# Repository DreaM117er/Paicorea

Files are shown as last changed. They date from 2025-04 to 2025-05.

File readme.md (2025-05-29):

# Paicorea

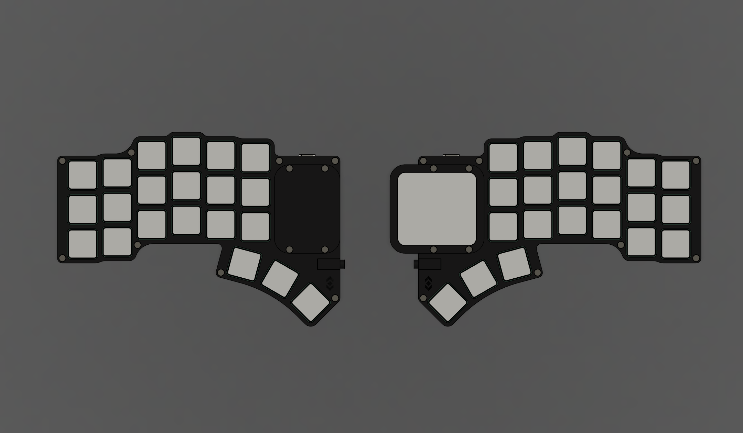
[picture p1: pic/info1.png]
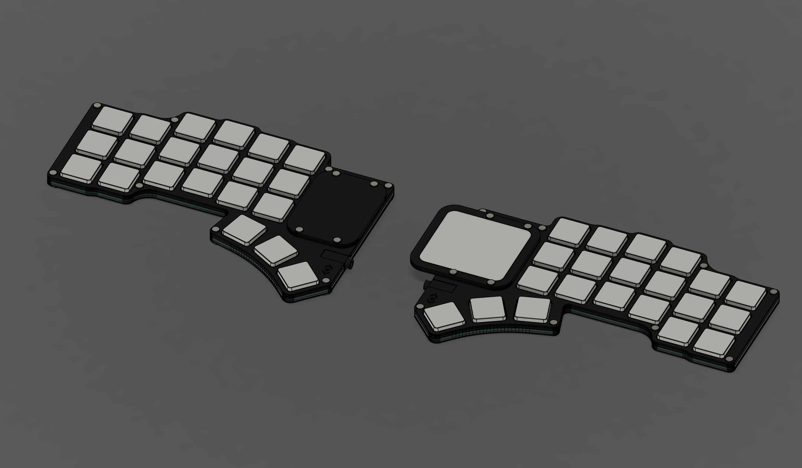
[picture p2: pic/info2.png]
|||
|--|--|
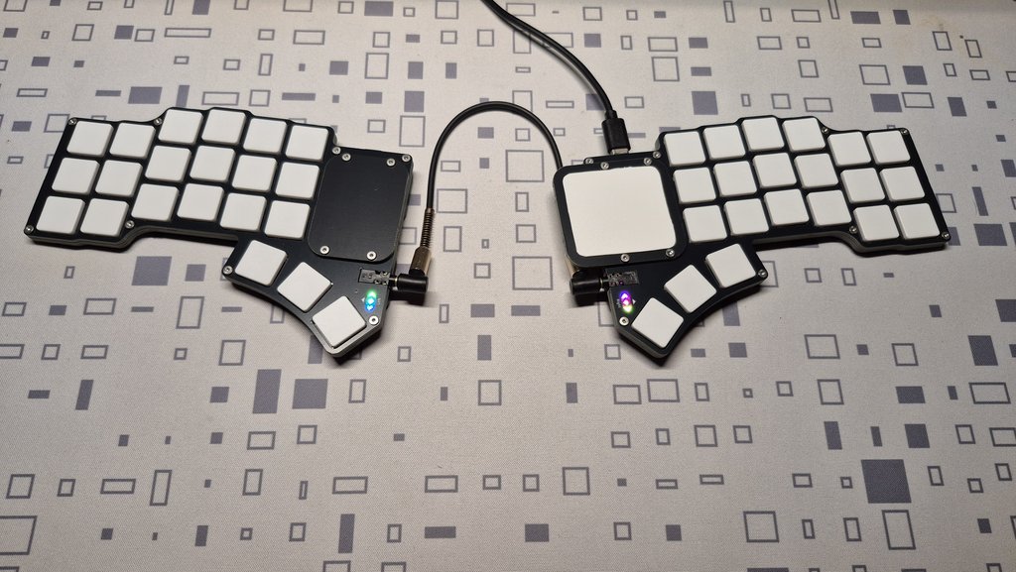
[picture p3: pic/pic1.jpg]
Keyboard1
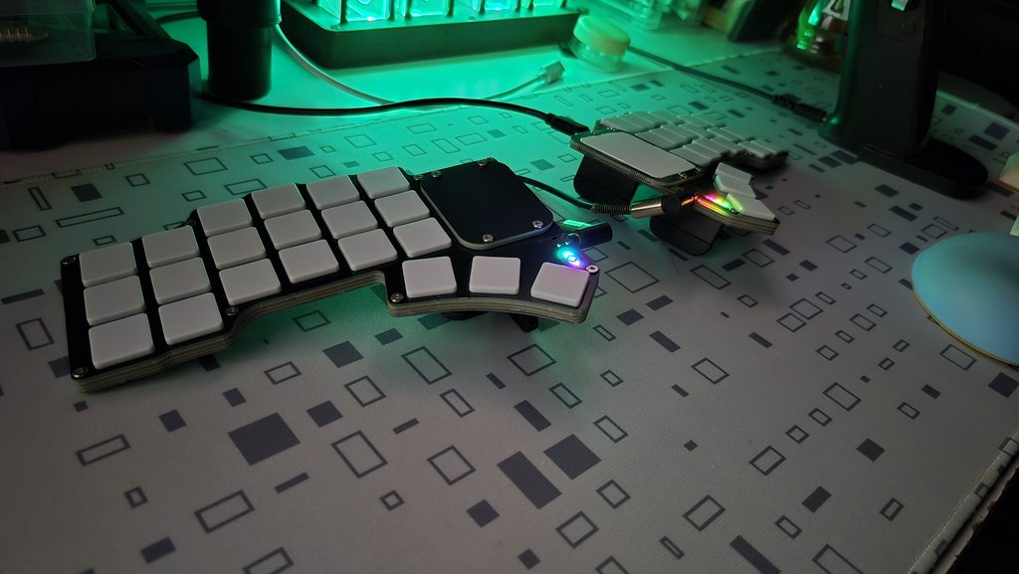
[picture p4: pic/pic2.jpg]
Keyboard2
|||

## 說明

Paicorea是一把專門為我而設計的分離式機械鍵盤，目的是為了讓鍵盤可以達到極度輕薄，又可以搭載`TPS43`這張由`Azoteq`公司生產製造的觸控板，滿足我的日常生活而使用。

它可以根據自己的需求選擇是否觸控板作為滑鼠使用；鍵盤按鍵則是使用`Kailh`生產製造的`PG1316S`作為它「目前」的按鍵使用，往後不排除會設計另一種機械鍵軸的版本來給自己做使用。

鍵盤的最初設計是像[AZCARD](https://github.com/palette-system/azcard)、[Bayleaf](https://kbd.news/Bayleaf-2610.html)、[Makefive](https://github.com/mikeholscher/zmk-config-mikefive)等一樣搭載`PG1316S`鍵軸的鍵盤都是以本體PCB作為底板壓縮厚度到3mm左右，但因為本人——也就是我自己，非常不喜歡使用無線設備（電池安全問題）的原因，一定得在鍵盤上搭載分離式鍵盤常見的`3.5mm TRRS座`，而我在這部分花了很多時間尋找能使用的零件，最後找到`PJ-381B`、`PJ-381C`、`PJ-399`等3款可以使用的沉板型號，再根據Datasheet跟3D設計，選擇了`PJ-381B`來使用。

在不想向下更換`2.5mm TRRS座`的前提下，很可惜地我只能將鍵盤厚度壓縮至5.5mm左右，但整體的結構讓我相當滿意。

使用`RP2040 Core-A`的原因——它跟用排線分離設計的`RP2040-Tiny`不同，我可以直接在PCB上拉USB2.0使用的USB-C口接線接在`RP2040 Core-A`上達到分離MCU跟USB-C的目的，而不用而外設計一個專門放置排線跟分離板的位置，而且又是厚度只有5.5mm的空間內。

最終從MCU——RP2040 Core-A（Raspberry Pi）中取Pi（π，Pai同音）、Core-A（corea），Paicorea就這麼誕生了。

## 使用材料

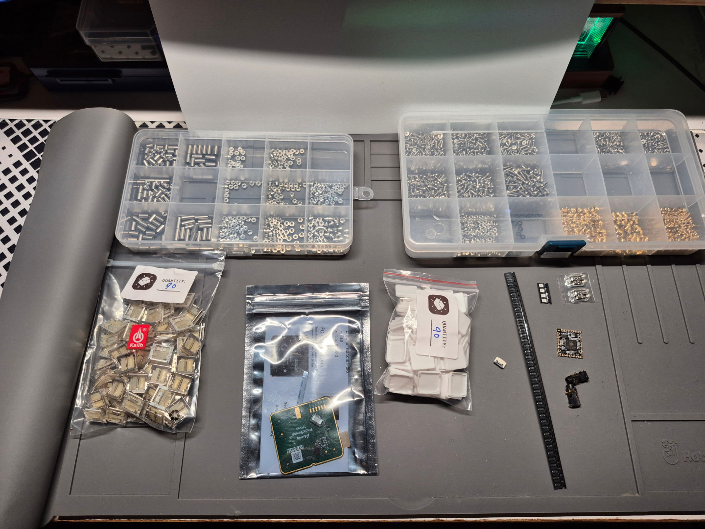
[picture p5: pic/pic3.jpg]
List


|名稱|規格|數量|備註|
|--|--|--|--|
|MCU|RP2040 Core-A|2|[Aliexpress Link](https://es.aliexpress.com/item/1005006101790601.html?channel=twinner)|
|Type-C母座|TYPE-C 16P CB1.6|2|沉板1.6mm|
|TRRS母座|PJ-381B|2|-|
|二極體|1N4148 `SOD-123`|42|-|
|貼片電阻|5.1K、`0603`|4|焊接後可支援C2C|
|鍵軸|Kailh PG1316S|42|-|
|鍵帽|適用PG1316S、`1u`大小|42|推薦用買的，3D列印需`留意邊角`圓弧|
|貼片銅柱|MAC8 TH0.8-2.0-M2（2.0）|16|-|
|貼片銅柱|MAC8 TH1.6-2.0-M2（2.0）|8|-|
|M2螺絲|牙長5mm、頭部`小於`ø4.2mm|24|-|
|矽膠自黏腳貼|ø8mm、厚度0.5-1.0mm|-|根據自己所需決定數量|
|緩衝墊|厚度0.5-0.8mm|-|矽膠或Poron等緩衝材料；需要裁切大小，請自行判斷需要多大面積|
|PVC板材|厚度0.8mm|-|觸控板面用，`A4`大小即可，需要裁切|
|0.5mm FFC排線座|6Pin|1|選配，安裝觸控板才需要|
|0.5mm FFC軟排線|6Pin、50mm、`AA同向`|1|選配，安裝觸控板才需要|
|觸控板|Azoteq TPS43-201A-S|1|選配|
|貼片LED燈|SK6805-2427（Micro）|6|選配，裝飾燈|

## 鍵盤結構

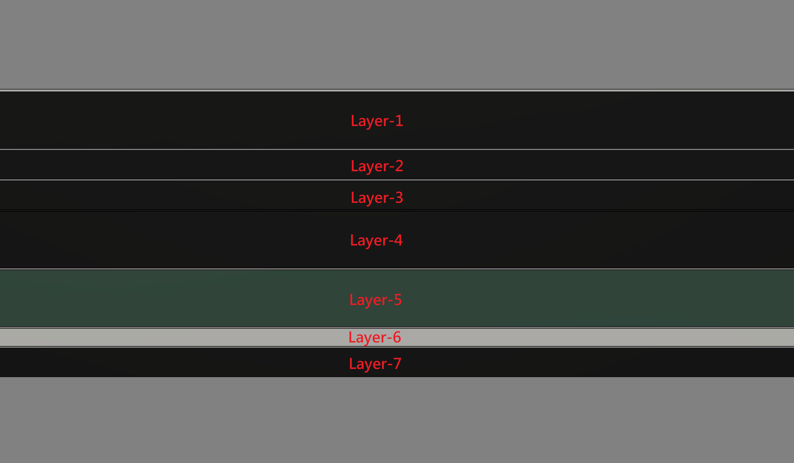
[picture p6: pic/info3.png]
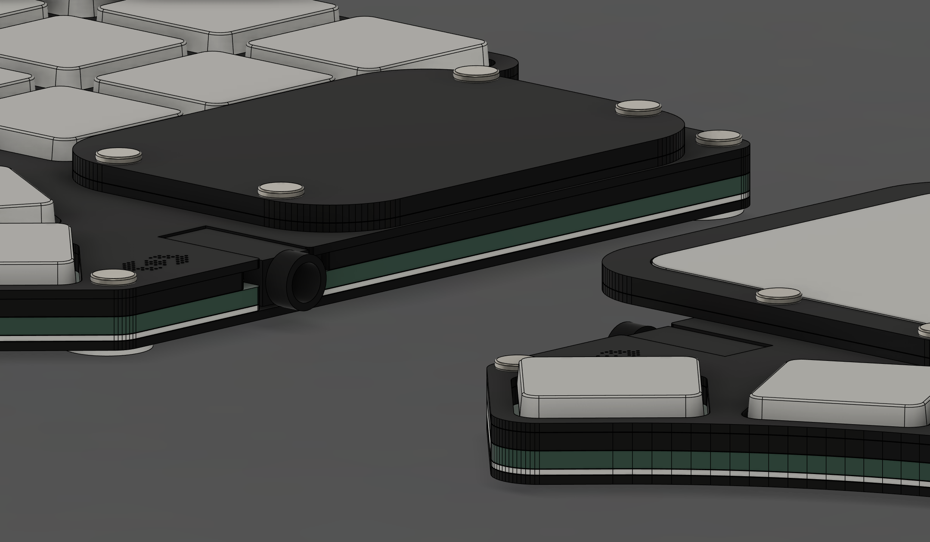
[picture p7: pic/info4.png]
|||
|--|--|

|順序|部件|厚度（mm）|備註|
|--|--|--|--|
|1|上蓋-A（Cover-A）、觸控板邊框-A（Track-A）|1.6|有無觸控板做選擇|
|2|上蓋-B（Cover-B）、觸控板邊框-B（Track-B）|0.8|有無觸控板做選擇|
|3|定位板（Plate）|0.8|-|
|4|間隙空間板（Body）|1.6|-|
|5|核心電路板（Main）|1.6|-|
|6|緩衝層（Frame）|0.5-0.8|自行裁切或使用電路板層都可|
|7|底板（Bottom）|0.8|-|

## 使用工具

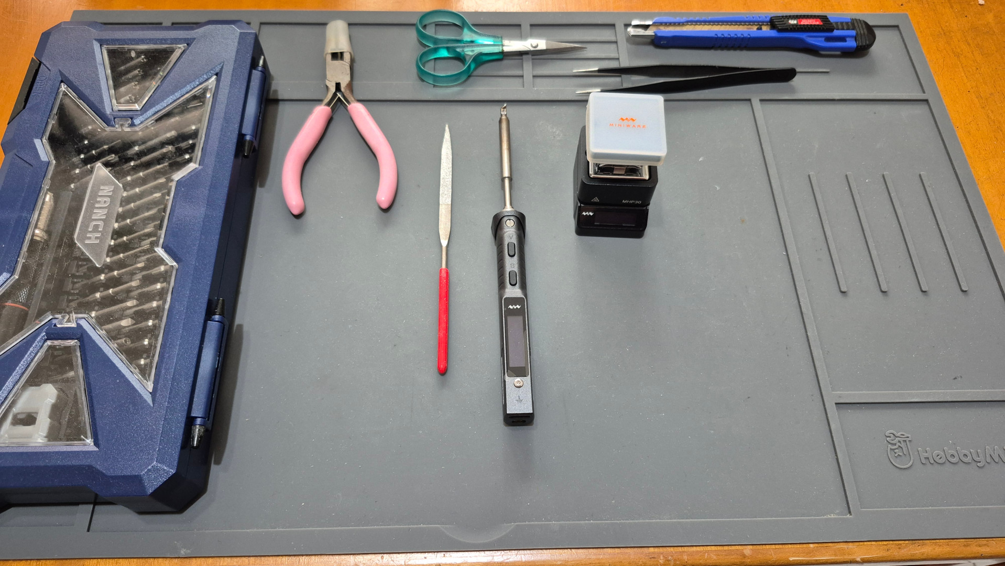
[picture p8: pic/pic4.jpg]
Tools


||名稱|使用場合|備註|
|--|--|--|--|
|1|電烙鐵|基本電路板焊接|修正焊錫使用，推薦使用K頭（刀頭）|
|2|熱風槍或加熱台|進階電路板焊接|擇一使用即可|
|3|針筒裝錫膏|進階電路板焊接||
|4|剪刀及美工刀|裁切膠帶及塑料板材||
|5|超薄超黏雙面膠|粘貼固定觸控板用|0.13-0.15mm厚度的即可|
|6|對應電路板顏色的簽字筆|邊框填色使用|可不需使用|
|7|防靜電金屬鑷子|進階電路板焊接、測試、精密操作||
|8|精密螺絲起子|-|對應螺絲規格使用|
|9|平口老虎鉗|分離拼接電路板時使用||
|10|銼刀|打磨電路板邊框時用||
|11|皮革打洞器|裁切矽膠墊使用|需要打ø4-4.5mm的孔|
|12|鉛筆或原子筆|裁切PVC塑膠板時使用||
|13|3秒膠或AB膠|固定層板使用||

## 組裝說明

### 注意事項

- 務必將所有元件都焊接在同一面。
- 焊接MCU、二極體、鍵軸及LED燈等... 都務必都要進行測試再做下一步動作。
- 只要有安裝方向的元件都會標示在電路板上，反之沒有安裝方向的元件什麼都不會標記。
- MCU上的THT焊盤孔用作定位使用。
- 使用焊接工具時務必注意安全，小心燙傷。

### 安裝順序

|圖示|說明|
|--|--|
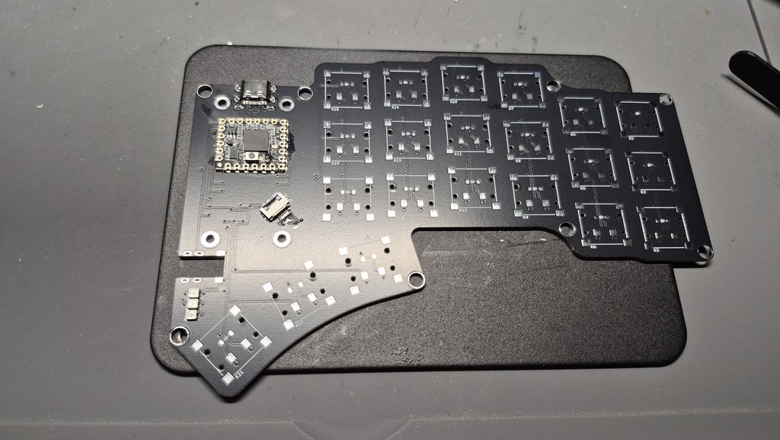
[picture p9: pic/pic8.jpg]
||首先將`MCU`、`USB-C`接口、`5.1K`電阻及`FFC`排線座焊接好。|
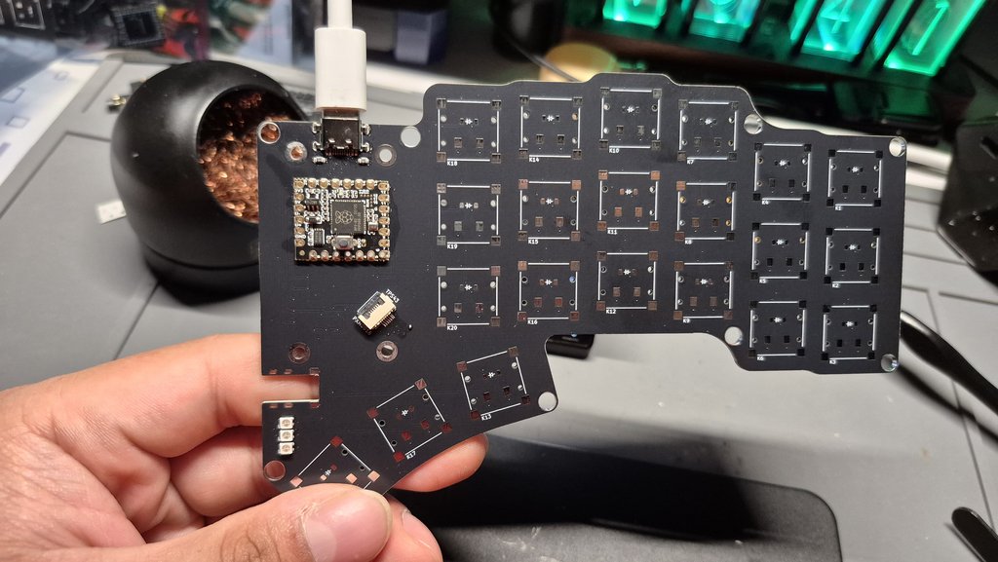
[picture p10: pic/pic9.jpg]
||連接電腦測試MCU的狀態，如果順利接通MCU的話，MCU上面的`橘紅色LED燈`會閃爍。|
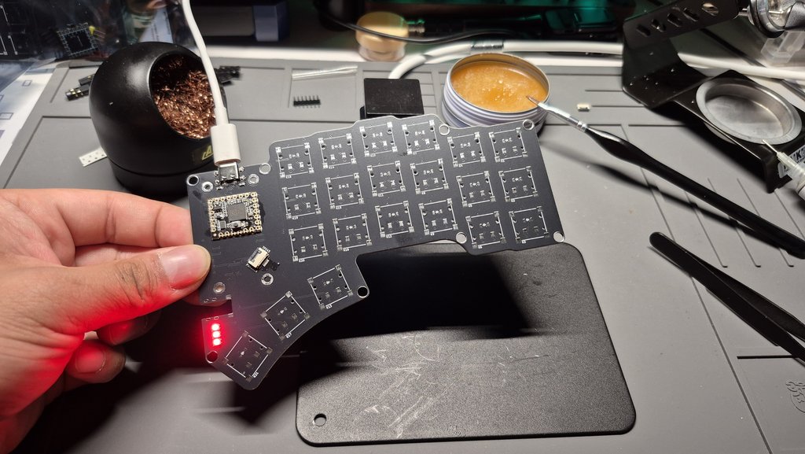
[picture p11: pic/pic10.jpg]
||請根據RP2040的燒錄方式將韌體燒錄至MCU，成功的話LED燈會亮，還有VIAL會成功讀取到鍵盤。|
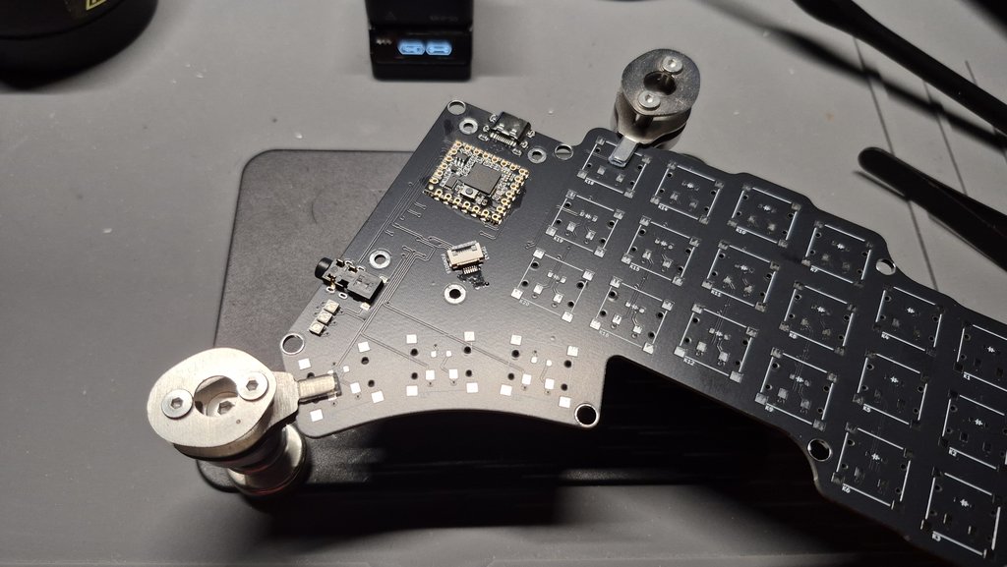
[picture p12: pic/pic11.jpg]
||再來焊接TRRS座。|
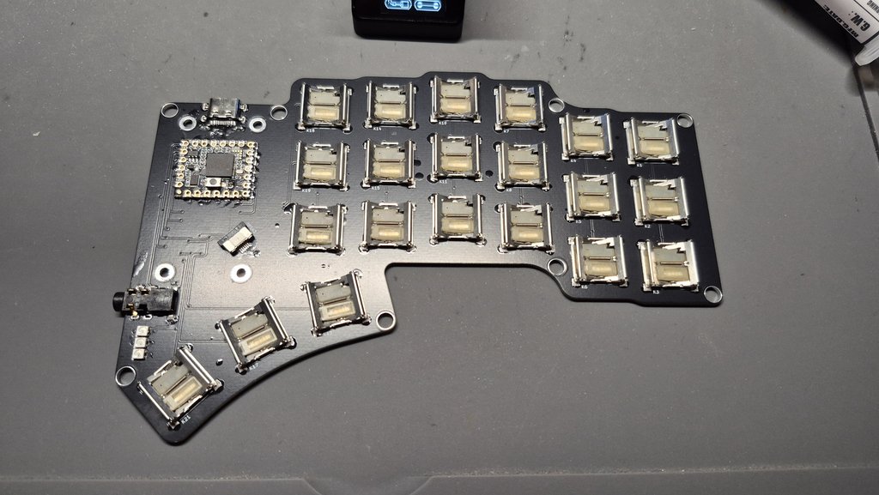
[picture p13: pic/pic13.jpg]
||接著按照順序將`1N4148`及`PG1316S`焊接起來，PG1316S的燈光孔是可以容下1N4148的，務必將二極體包覆在軸燈燈孔裡面。|
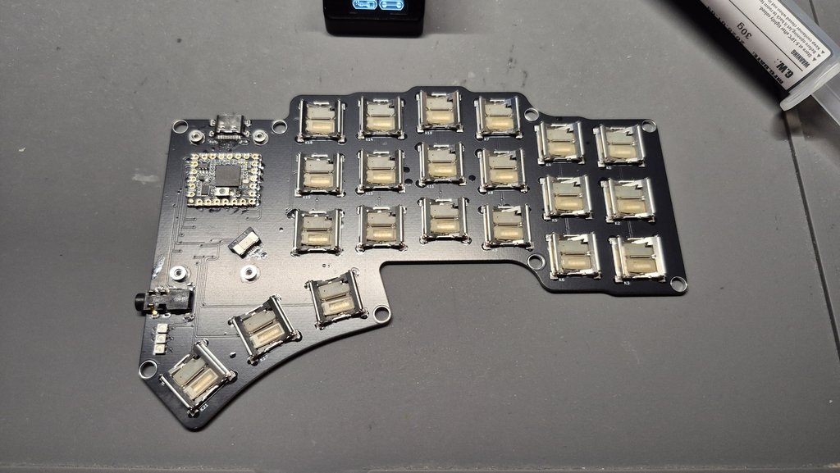
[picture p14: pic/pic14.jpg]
||然後將貼片銅柱（`MAC8 TH1.6-2.0-M2`）焊接上去。|
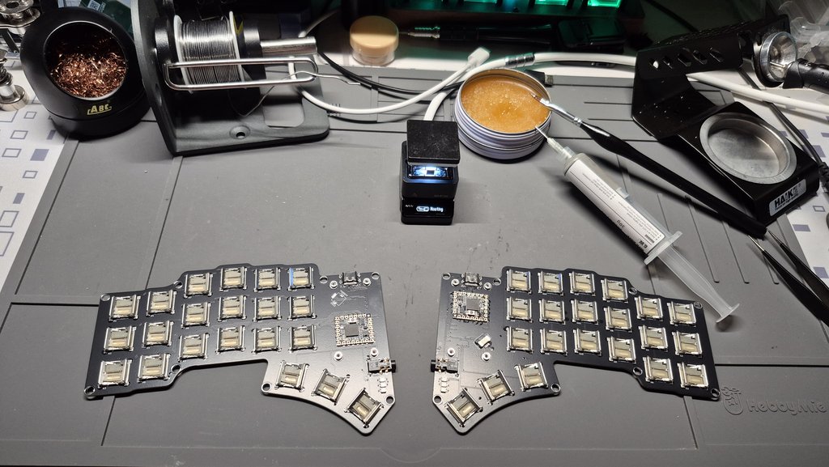
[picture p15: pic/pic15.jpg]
||接著將另一側鍵盤也焊好。|
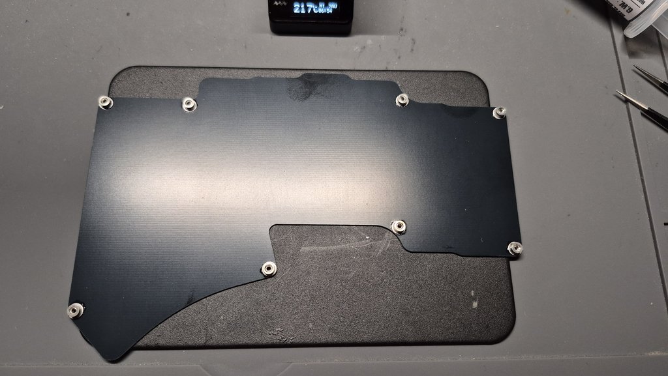
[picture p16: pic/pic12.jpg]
||再來將底板（Bottom）的貼片銅柱（`MAC8 TH0.8-2.0-M2`）也焊接固定好。|
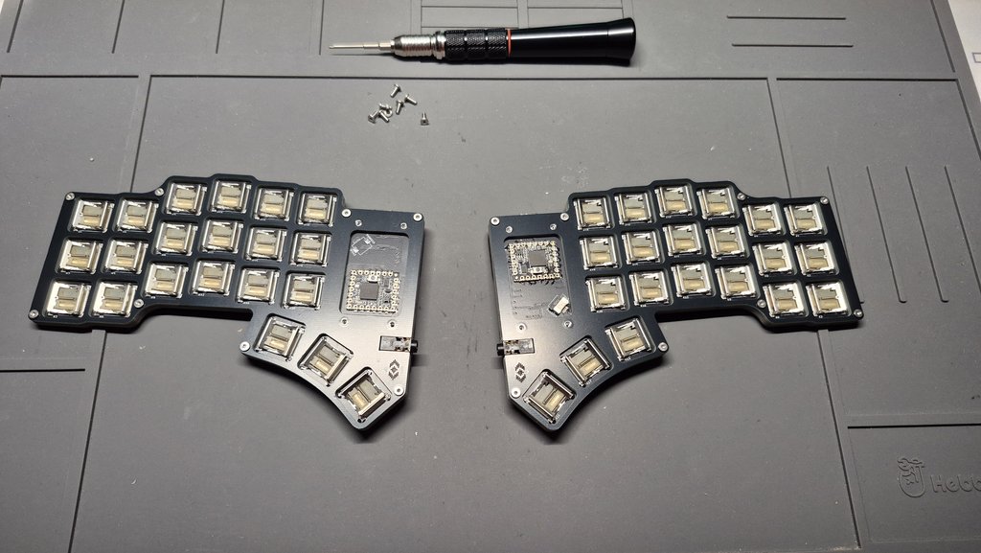
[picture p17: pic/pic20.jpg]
||接著依照底板（Bottom）、緩衝層（Frame）、電路板（Main）、間隙（Body）、定位板（Plate）的順序將鍵盤疊好，再把鍵盤外側的螺絲鎖上去固定。|
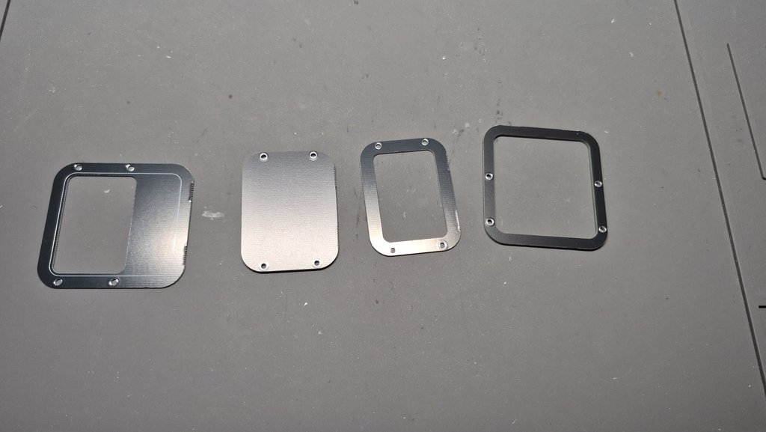
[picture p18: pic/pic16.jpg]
||將Cover-A、Cover-B、Track-A、Track-B用工具剝下來。|
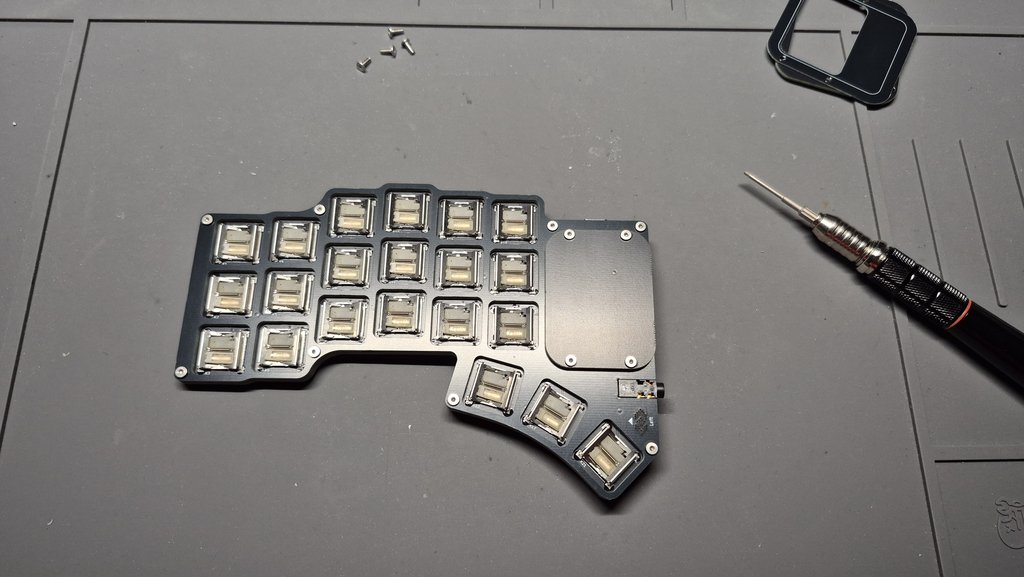
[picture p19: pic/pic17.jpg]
||然後將其中一側的Cover蓋起來用螺絲鎖好，完成其中一邊，如果不需要安裝觸控板就把兩側鍵盤都鎖上Cover就完成了。|
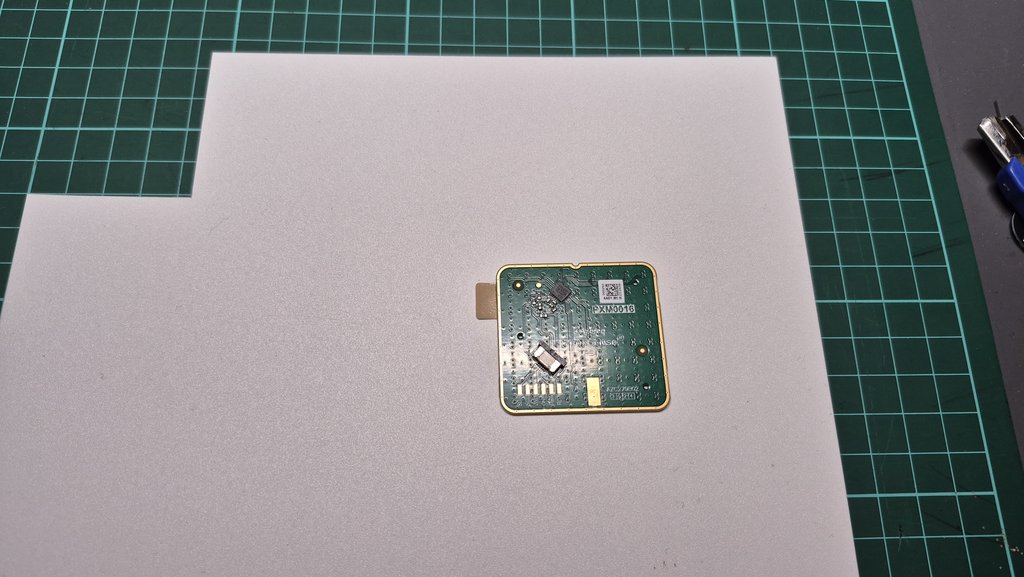
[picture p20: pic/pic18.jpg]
||觸控板的部分可以選擇使用列印或自己切觸控板Cover。|
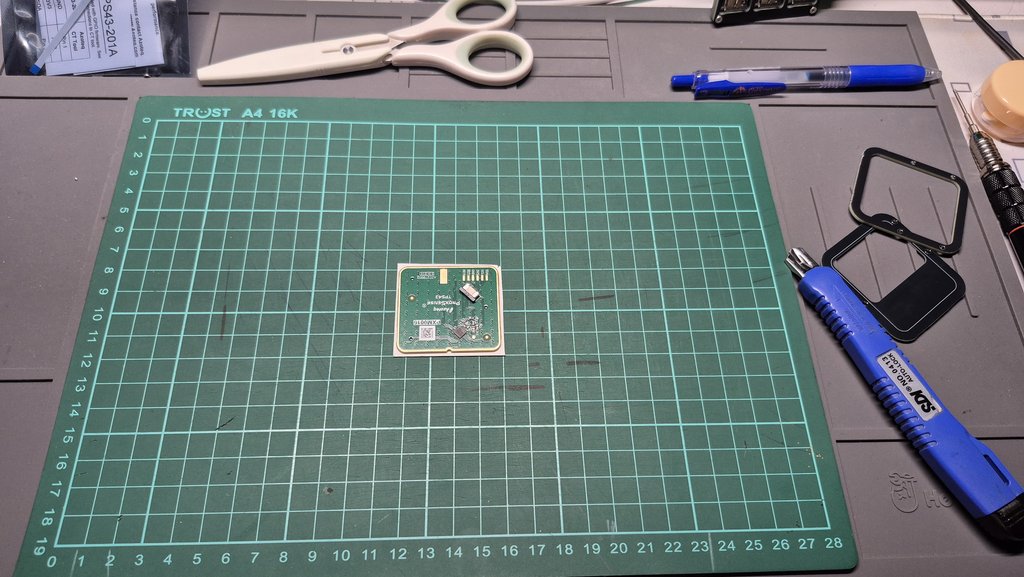
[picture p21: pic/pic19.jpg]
||首先將觸控板上的3M貼紙撕下來貼在8mm的PVC板材上後裁切下來，再把多餘的邊切除。|
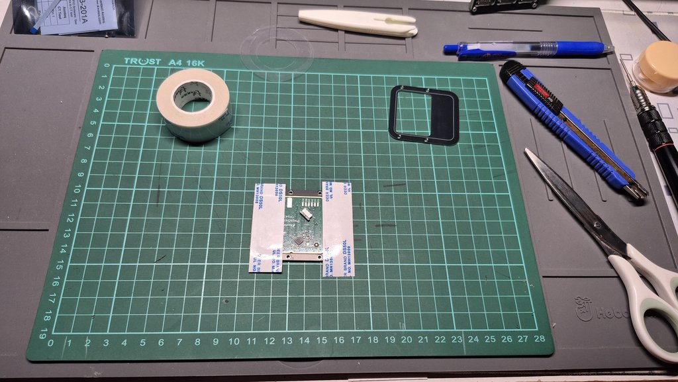
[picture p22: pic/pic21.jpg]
||好了之後將Track-A固定好，貼上超黏雙面膠。|
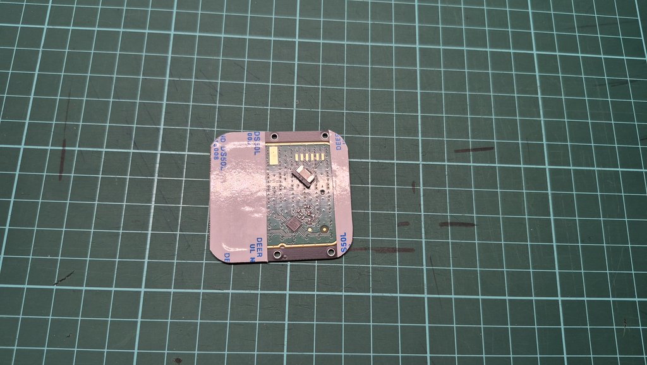
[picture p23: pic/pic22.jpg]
||一樣切除多餘的膠。|
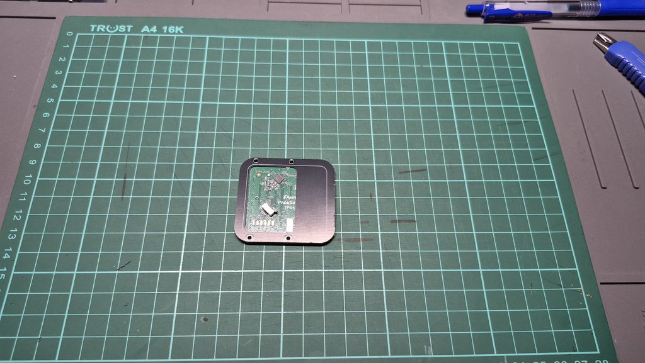
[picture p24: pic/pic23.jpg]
||撕下膠的另一面之後，將A、B合併在一起。|
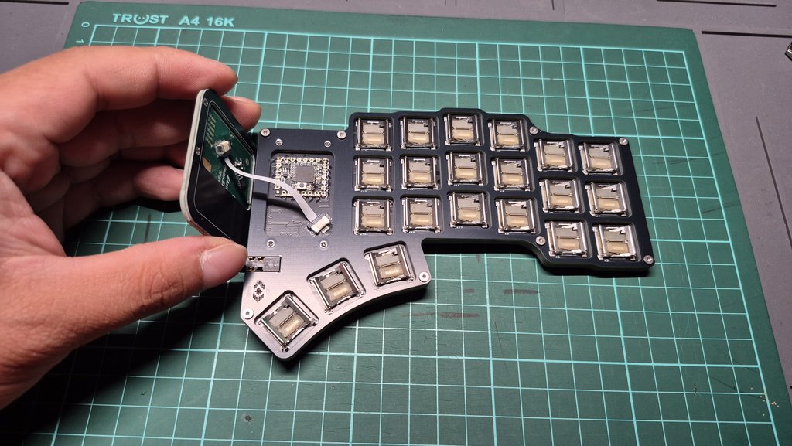
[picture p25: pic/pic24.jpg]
||接上排線，稍微彎折收納一下排線。|
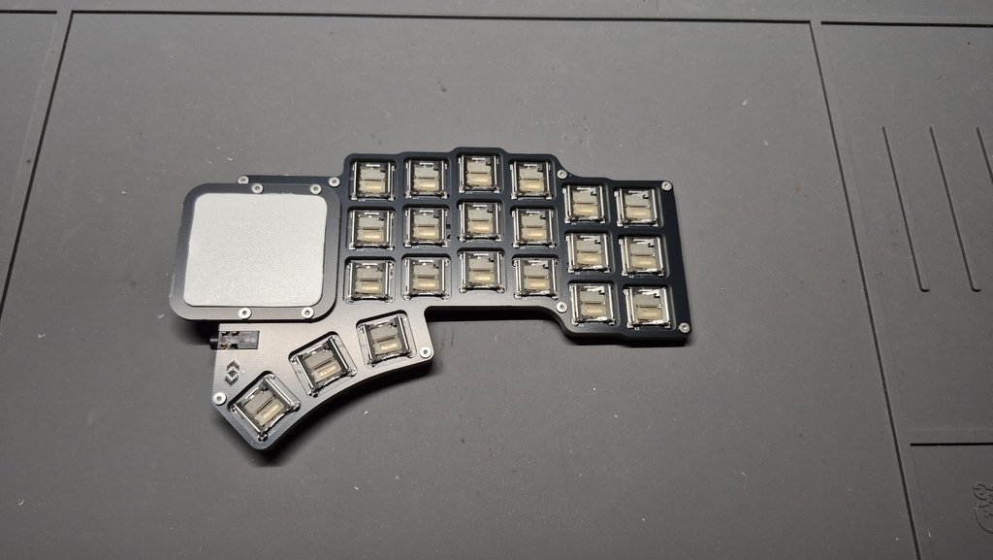
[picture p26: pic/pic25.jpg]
||鎖上螺絲。|
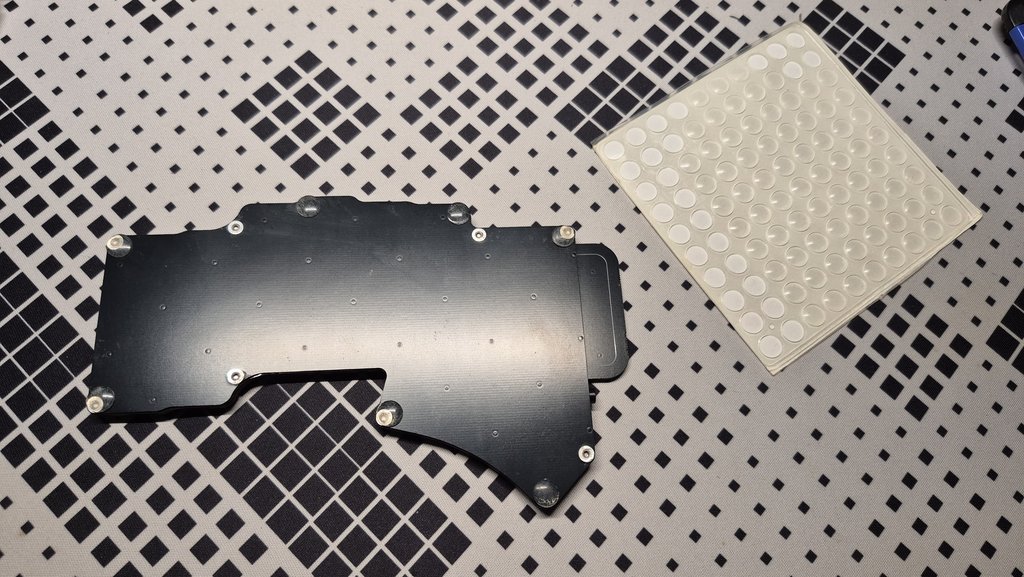
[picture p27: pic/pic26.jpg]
||然後翻到背面貼上腳貼或自行DIY上Tending。|
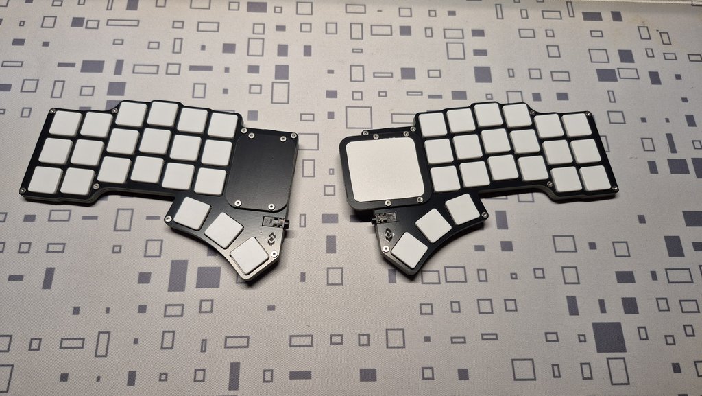
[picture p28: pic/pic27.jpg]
||安裝鍵帽之後就完成啦。|

## 參考資料

### 鍵盤
- [AZCARD](https://github.com/palette-system/azcard)：結構部分及銅柱元件參照。
- [Makefive](https://github.com/mikeholscher/zmk-config-mikefive)：結構部分。
- [Bayleaf](https://kbd.news/Bayleaf-2610.html)：結構部分。
- [Corne v4](https://github.com/foostan/crkbd)：TRRS連接座、PCB走線參照。
- [X：おおやけハジメ](https://x.com/digitarhythm)——[未完成"V1"](https://x.com/digitarhythm/status/1908885665695363132)：
PCB走線參照。

### 部落格、網頁、參考說明書
- [Holykeeb](https://holykeebs.com/)、[Holykeeb.Docs](https://docs.holykeebs.com/guides/touchpad-module/)。
- [74th Blog](https://74th.hateblo.jp/entry/testing-TPS43-201A-S)
- [Reddit: mikefive, a Kailh PG1316 keyboard](https://www.reddit.com/r/ErgoMechKeyboards/comments/1cfg3vr/mikefive_a_kailh_pg1316_keyboard/)
- [KBD.News](https://kbd.news/)

### 規格書
- PJ-381B、PJ-381-C、PJ-399。
- TYPE-C 16P CB1.6。
- MAC8 THXX-XX-M2。
- SK6805-2427。
- Kailh PG1316S & Keycap。
- Azoteq TPS43-201A-S。

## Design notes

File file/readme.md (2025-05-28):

## 注意事項

- 公差設定0.05mm。
- 3D模型由於沒有變更太多東西，相容性不影響，因此我就沒有更新新的上去了。
- 結構為標準電路板堆疊，因此才能夠將鍵盤壓縮至10mm以內。
- 底板經過Prototype測試，厚度不允許從1.6mm降低至0.8mm，TRRS線會摩擦桌面，實際使用上會有問題。
- 裁切能力有限的夥伴，請一律定製電路板外殼來製作鍵盤，厚度不會差異太多。

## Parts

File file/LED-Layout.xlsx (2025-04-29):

 | X | Y | cal.X | cal.Y
 | 325.503 | 83.511 | 224 | 64
L01 | 136.454 | 56.89 | 93.90296249 | 43.59856785
L02 | 136.454 | 59.79 | 93.90296249 | 45.82102956
L03 | 136.454 | 70.32 | 93.90296249 | 53.89086468
L04 | 189.049 | 56.89 | 130.0970375 | 43.59856785
L05 | 189.049 | 59.79 | 130.0970375 | 45.82102956
L06 | 189.049 | 62.69 | 130.0970375 | 48.04349128

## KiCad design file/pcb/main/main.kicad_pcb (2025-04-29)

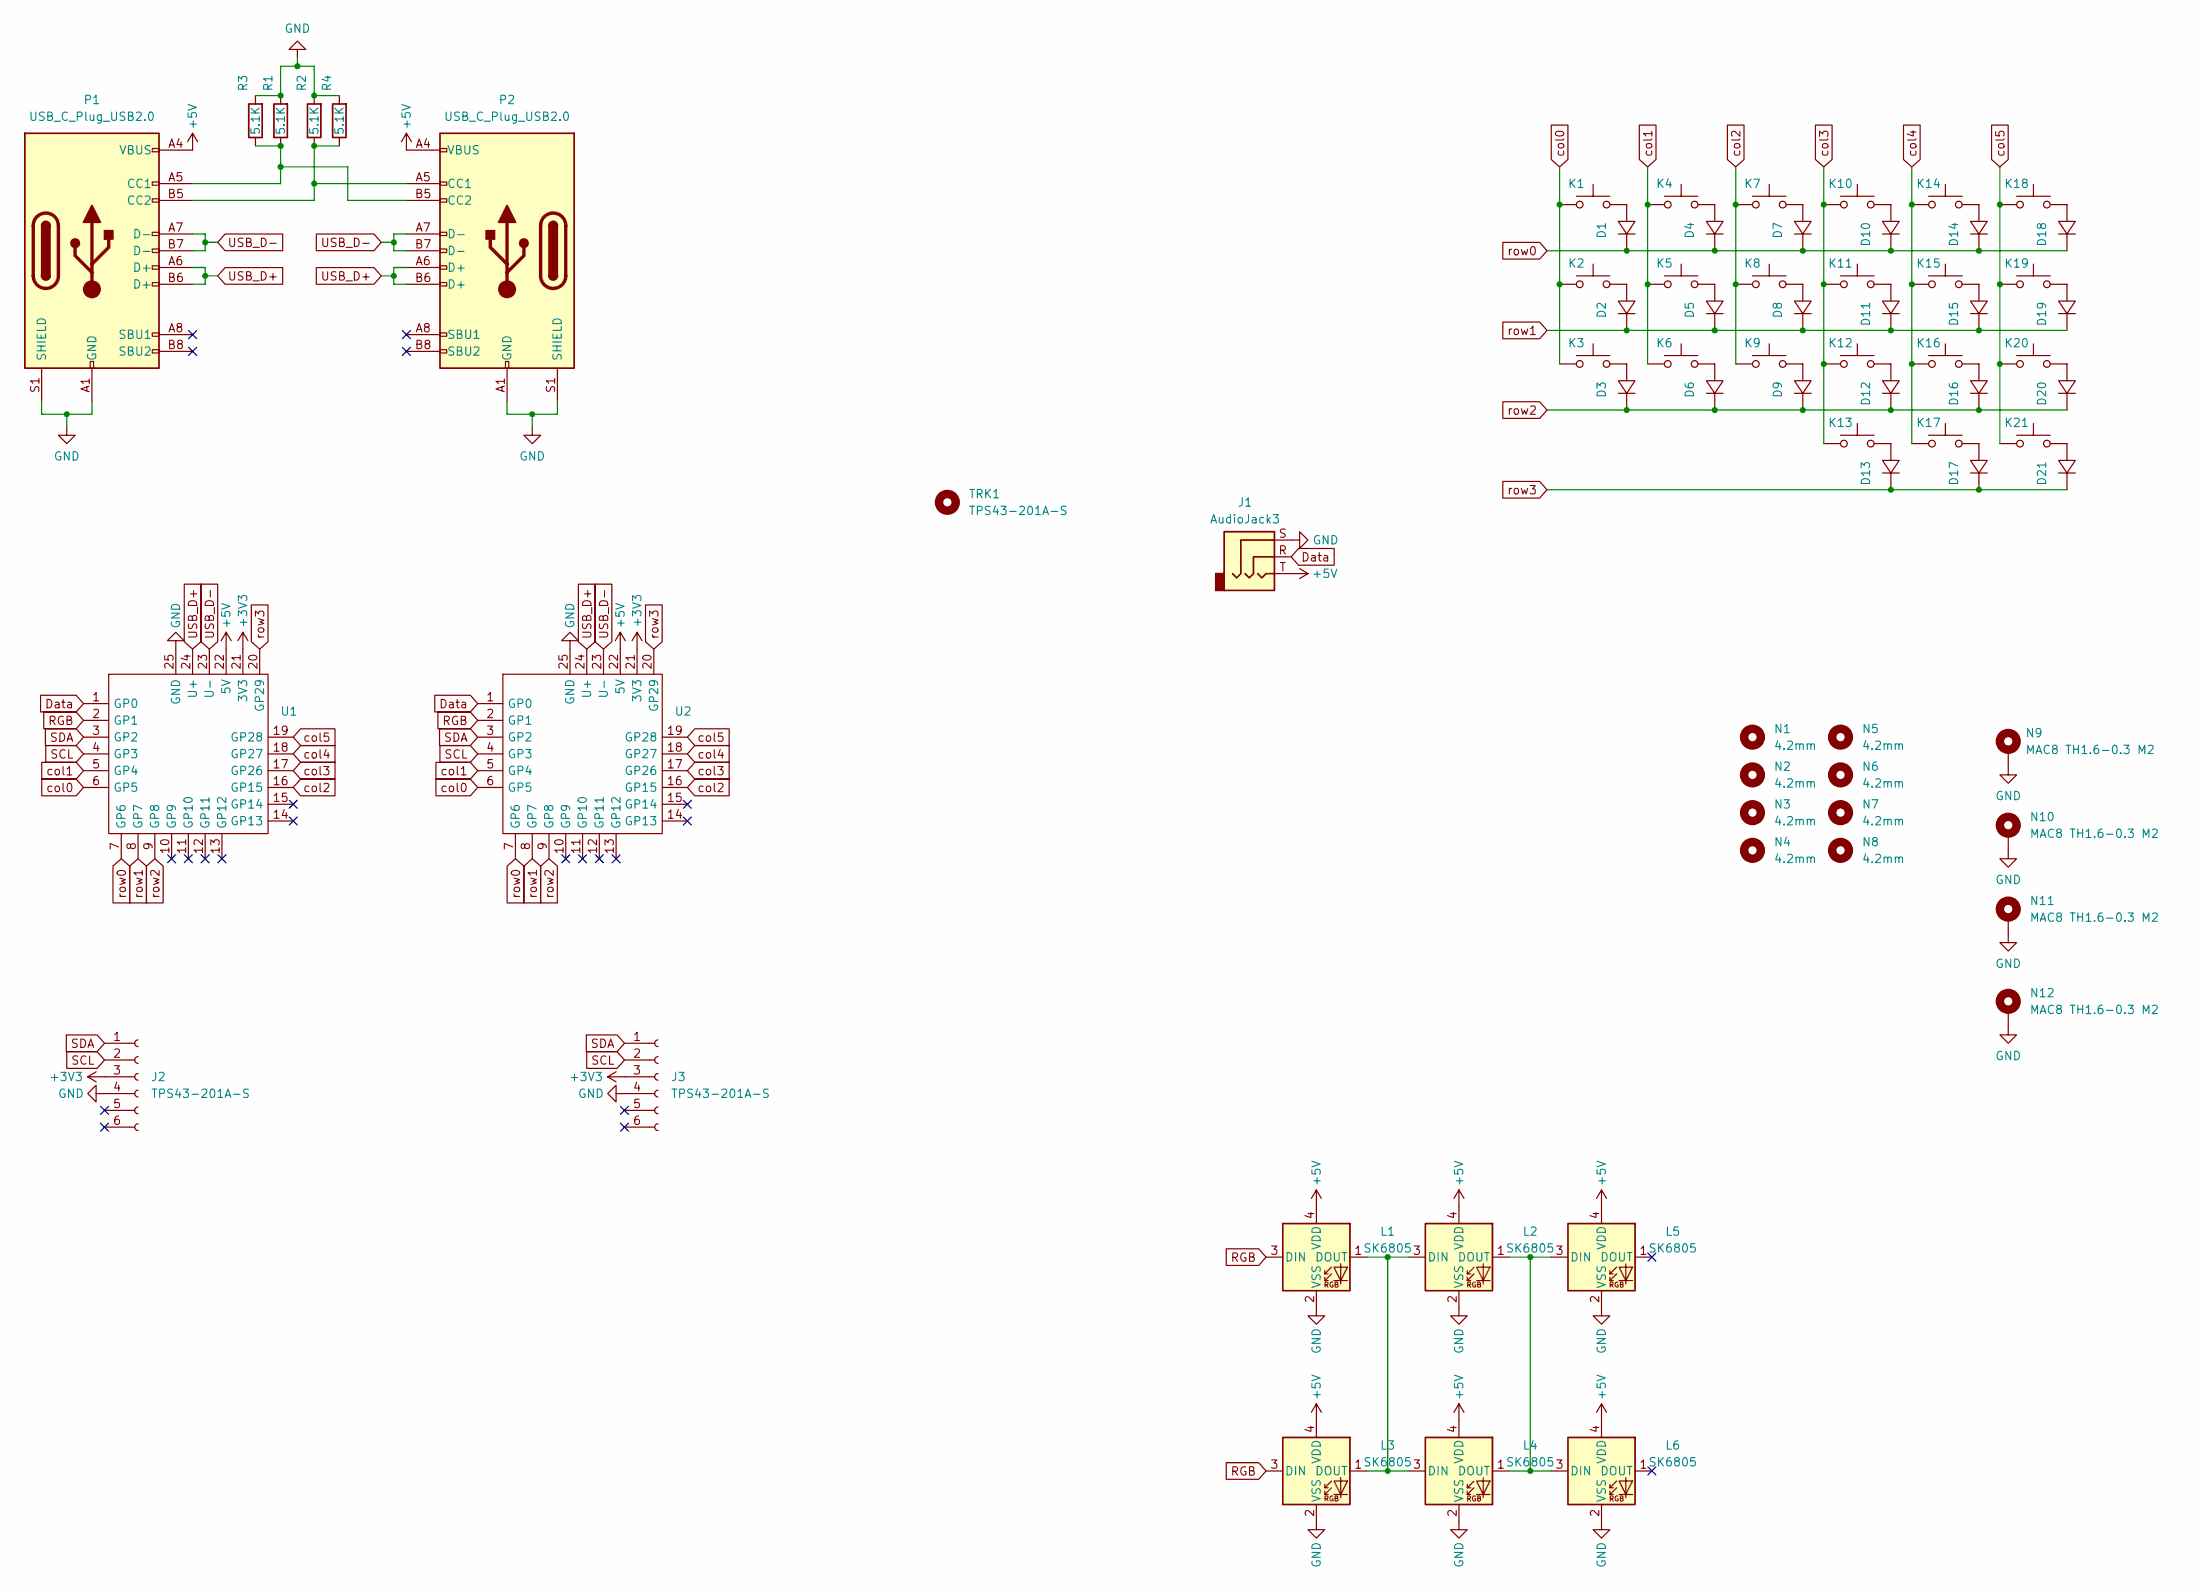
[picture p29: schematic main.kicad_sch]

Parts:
D1, D2, D3, D4, D5, D6, D7, D8, D9, D10, D11, D12, D13, D14, D15, D16, D17, D18, D19, D20, D21: 1N4148_SMD; D_SOD-123_dual
J1: AudioJack3; TRRS-PJ-381-BB_6P_Dual
J2, J3: TPS43-201A-S; Hirose_FH12-6S-0.5SH_1x06-1MP_P0.50mm_Horizontal
K1, K2, K3, K4, K5, K6, K7, K8, K9, K10, K11, K12, K13, K14, K15, K16, K17, K18, K19, K20, K21: PG1316S; SW_Kailh_PG1316S_1.00u_Dual2
L1, L2, L3, L4, L5, L6: SK6805; LED_SK6805_PLCC4_2.4x2.7mm_P1.3mm
N1, N2, N3, N4, N5, N6, N7, N8: 4.2mm; MAC8_TH0816-XX-M2-NPTHhole
N9, N10, N11, N12: MAC8 TH1.6-0.3 M2; MAC8_TH0816-XX-M2-Dual_Pad
P1, P2: USB_C_Plug_USB2.0; USB_C_16P_MID_MOUT_SR_Molex
R1, R2, R3, R4: 5.1K; R_0603_1608Metric
TRK1: TPS43-201A-S; Azoteq_TPS43_201A_S
U1, U2: MCU_RP2040_CoreA_SMD; MCU_RP2040CoreA_SMD

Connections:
+3V3: J2.3, J3.3, U1.21 (3V3), U2.21 (3V3)
+5V: J1.T, L1.4 (VDD), L2.4 (VDD), L3.4 (VDD), L4.4 (VDD), L5.4 (VDD), L6.4 (VDD), P1.A4 (VBUS), P1.A9 (VBUS), P1.B4 (VBUS), P1.B9 (VBUS), P2.A4 (VBUS), P2.A9 (VBUS), P2.B4 (VBUS), P2.B9 (VBUS), U1.22 (5V), U2.22 (5V)
Data: J1.R, U1.1 (GP0), U2.1 (GP0)
GND: J1.S, J2.4, J3.4, L1.2 (VSS), L2.2 (VSS), L3.2 (VSS), L4.2 (VSS), L5.2 (VSS), L6.2 (VSS), N9.1, N10.1, N11.1, N12.1, P1.A1 (GND), P1.A12 (GND), P1.B1 (GND), P1.B12 (GND), P1.S1 (SHIELD), P2.A1 (GND), P2.A12 (GND), P2.B1 (GND), P2.B12 (GND), P2.S1 (SHIELD), R1.2, R2.2, R3.2, R4.2, U1.25 (GND), U2.25 (GND)
unnamed: D1.2, K1.2
unnamed: D2.2, K2.2
unnamed: D3.2, K3.2
unnamed: D4.2, K4.2
unnamed: D5.2, K5.2
unnamed: D6.2, K6.2
unnamed: D7.2, K7.2
unnamed: D8.2, K8.2
unnamed: D9.2, K9.2
unnamed: D10.2, K10.2
unnamed: D11.2, K11.2
unnamed: D12.2, K12.2
unnamed: D13.2, K13.2
unnamed: D14.2, K14.2
unnamed: D15.2, K15.2
unnamed: D16.2, K16.2
unnamed: D17.2, K17.2
unnamed: D18.2, K18.2
unnamed: D19.2, K19.2
unnamed: D20.2, K20.2
unnamed: D21.2, K21.2
unnamed: L1.1 (DOUT), L2.3 (DIN), L3.1 (DOUT), L4.3 (DIN)
unnamed: L2.1 (DOUT), L4.1 (DOUT), L5.3 (DIN), L6.3 (DIN)
unnamed: P1.A5 (CC1), P2.B5 (CC2), R1.1, R3.1
unnamed: P1.B5 (CC2), P2.A5 (CC1), R2.1, R4.1
RGB: L1.3 (DIN), L3.3 (DIN), U1.2 (GP1), U2.2 (GP1)
SCL: J2.2, J3.2, U1.4 (GP3), U2.4 (GP3)
SDA: J2.1, J3.1, U1.3 (GP2), U2.3 (GP2)
USB_D+: P1.A6 (D+), P1.B6 (D+), P2.A6 (D+), P2.B6 (D+), U1.24 (U+), U2.24 (U+)
USB_D-: P1.A7 (D-), P1.B7 (D-), P2.A7 (D-), P2.B7 (D-), U1.23 (U-), U2.23 (U-)
col0: K1.1, K2.1, K3.1, U1.6 (GP5), U2.6 (GP5)
col1: K4.1, K5.1, K6.1, U1.5 (GP4), U2.5 (GP4)
col2: K7.1, K8.1, K9.1, U1.16 (GP15), U2.16 (GP15)
col3: K10.1, K11.1, K12.1, K13.1, U1.17 (GP26), U2.17 (GP26)
col4: K14.1, K15.1, K16.1, K17.1, U1.18 (GP27), U2.18 (GP27)
col5: K18.1, K19.1, K20.1, K21.1, U1.19 (GP28), U2.19 (GP28)
row0: D1.1, D4.1, D7.1, D10.1, D14.1, D18.1, U1.7 (GP6), U2.7 (GP6)
row1: D2.1, D5.1, D8.1, D11.1, D15.1, D19.1, U1.8 (GP7), U2.8 (GP7)
row2: D3.1, D6.1, D9.1, D12.1, D16.1, D20.1, U1.9 (GP8), U2.9 (GP8)
row3: D13.1, D17.1, D21.1, U1.20 (GP29), U2.20 (GP29)

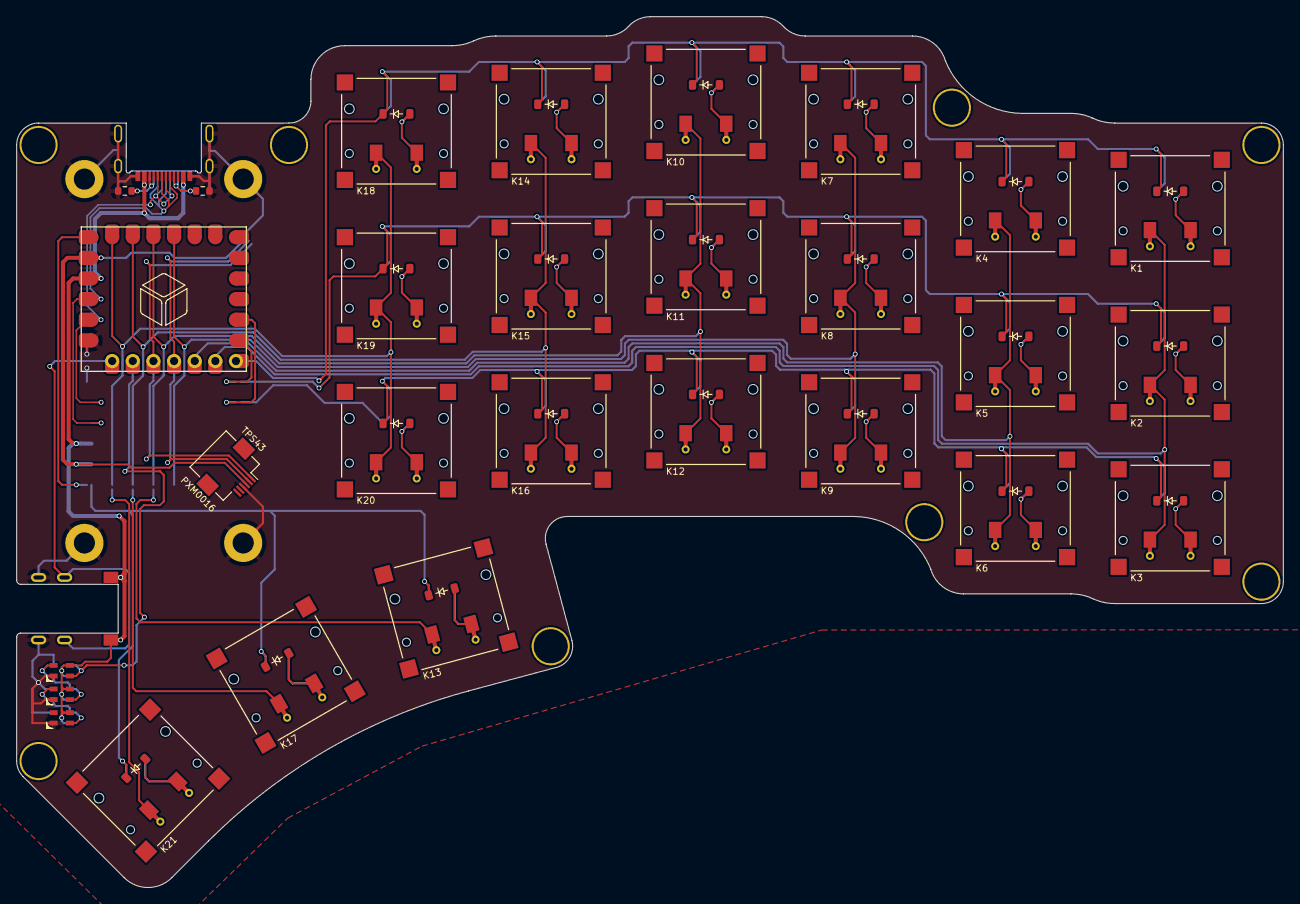
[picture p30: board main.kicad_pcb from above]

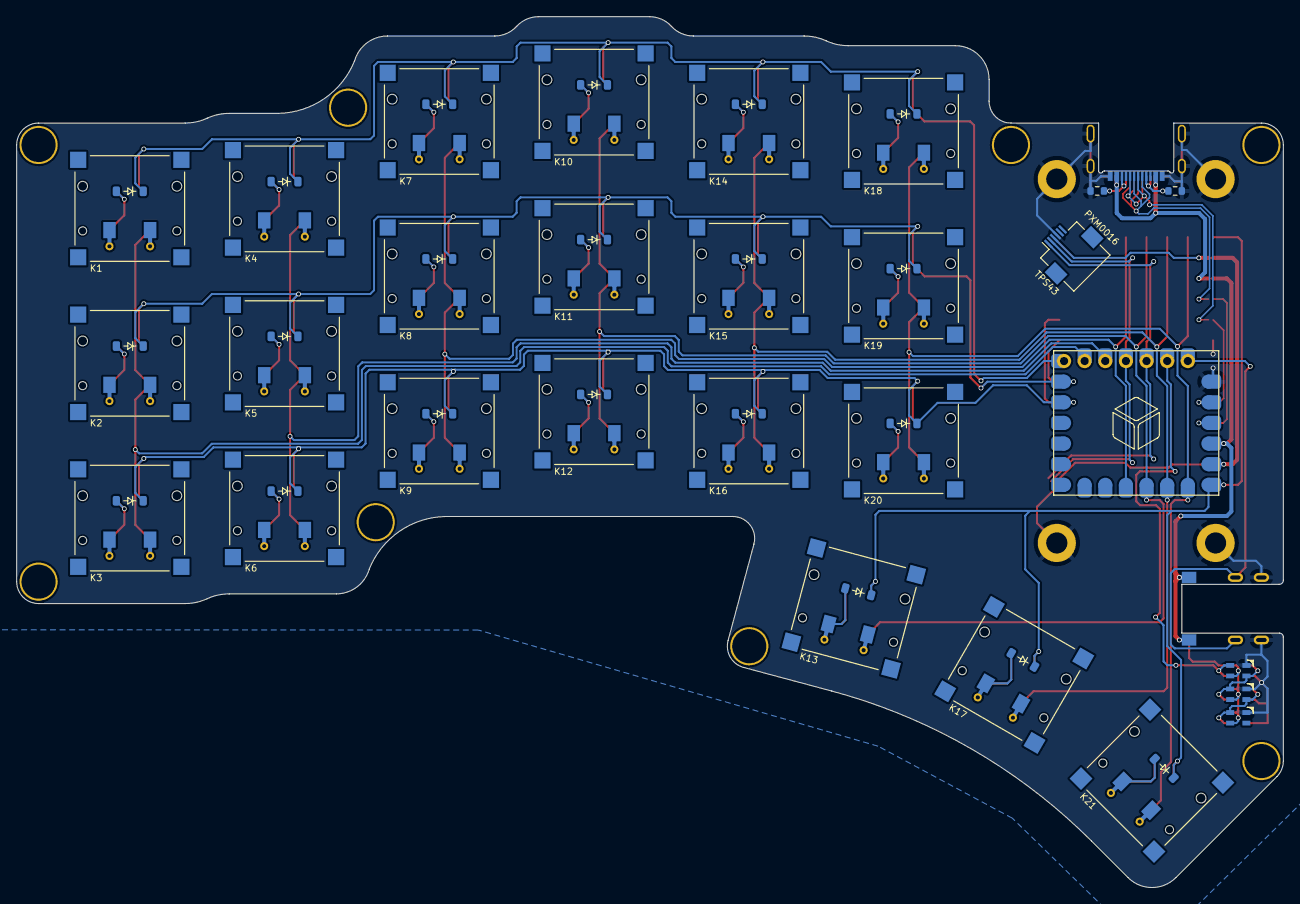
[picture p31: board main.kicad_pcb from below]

Board: 2 copper layers, 155.9 x 107.2 mm, 72 parts (8 on the bottom side), 44 nets.

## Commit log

2025-04-20 update 3d & pcb files
    [body.kicad_pcb, body.kicad_sch, body2.kicad_pcb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]
2025-04-24 add rgb file
    [LED-Layout.xlsx]
2025-04-29 update prototype files
    [LED-Layout.xlsx, pad.kicad_pcb, pad.kicad_sch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]
2025-04-29 set the new files
    [body.kicad_pcb, main.kicad_pcb, main.kicad_sch]
2025-04-29 update new LED layout
    [LED-Layout.xlsx]
2025-04-29 update frame
    [Frame.kicad_pcb, Frame.kicad_sch]
